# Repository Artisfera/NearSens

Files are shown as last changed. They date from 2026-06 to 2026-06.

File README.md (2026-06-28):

# NearSens

NearSens is a small contactless distance meter for short range measurement. It uses a 40 kHz ultrasonic transmitter and receiver, an ATtiny1626 microcontroller, an analog receiver path, and a four-digit LCD.

The current prototype is built around a practical 5 V setup and a useful range of about 100 to 500 mm. The goal was not to make a universal sensor module. The goal was to make a simple device that can be built, tested, calibrated, and understood without hiding the hardware behind a black box.

## Main assumptions

- external 5 V DC supply
- ultrasonic time-of-flight measurement
- practical range around 100 to 500 mm
- four-digit LCD readout
- simple two-button interface
- five-point calibration stored in EEPROM
- low part count and low cost where possible
- firmware kept readable enough to debug on real hardware

## How it works

The microcontroller sends a short ultrasonic burst through the transmitter driver. The receiver picks up the echo, the analog path amplifies and filters it, and the firmware searches for a valid reflected signal in the expected time window.

The distance is calculated from echo return time. Calibration points at 100, 200, 300, 400 and 500 mm are stored in EEPROM and used to correct later measurements.

## Hardware overview

The main hardware blocks are:

- ATtiny1626 microcontroller
- ST232CDR used as the ultrasonic transmitter driver
- 40 kHz ultrasonic transmitter and receiver
- LM324 receiver path
- MC14543BDG LCD drivers
- DE117 four-digit LCD
- two tactile buttons, TS3 and TS4
- external 5 V input through PS1

R4 is a 220 ohm THT resistor added in the receiver/filter path after testing. It is listed separately in the BOM.

## Repository layout

```text
docs/
  NearSens_project_documentation.pdf
  NearSens_user_guide.pdf

hardware/
  schematic/   schematic preview and EasyEDA source
  pcb/         PCB source, outline and previews
  gerber/      PCB production files
  enclosure/   STL models

firmware/
  NearSens_1.0.0/   current firmware source

bom/
  NearSens_BOM_v1.0.0.csv

revisions/
  earlier schematic, PCB, firmware and enclosure versions

JOURNAL.md
  build log exported from Stasis
```

## Documentation

Start here:

- [Project documentation](docs/NearSens_project_documentation.pdf)
- [Use and calibration guide](docs/NearSens_user_guide.pdf)
- [Bill of materials](bom/NearSens_BOM_v1.0.0.csv)

The `revisions` folder is an archive of earlier work. The current files are in `docs`, `hardware`, `firmware` and `bom`.

## Firmware

Current firmware is in:

```text
firmware/NearSens_1.0.0/
```

It was prepared for Arduino IDE with the megaTinyCore package and ATtiny1626 running at 5 MHz.

Main controls:

- TS3 makes a measurement
- TS4 toggles the 75 mm reference correction
- holding TS3 and TS4 enters calibration
- five quick TS3 clicks toggle RAW mode

Normal use does not need a computer. A 5 V DC supply is enough to power the prototype and take measurements.

## Calibration

Calibration uses five points:

```text
100 mm
200 mm
300 mm
400 mm
500 mm
```

Use a flat, hard target placed perpendicular to the ultrasonic transducers. Soft materials, angled surfaces and nearby reflections can make the result unstable.

## Status

This repository contains the v1.0.0 prototype documentation, firmware and hardware files. It is a working prototype, not a finished commercial product. Some parts of the history are kept in `revisions` because they show how the design changed over time.

## License

NearSens is source-available for non-commercial community use.

Firmware and source code are licensed under the PolyForm Noncommercial License 1.0.0. The official license text is in [LICENSE](LICENSE) and [LICENSES/PolyForm-Noncommercial-1.0.0.txt](LICENSES/PolyForm-Noncommercial-1.0.0.txt).

Hardware design files, PCB files, CAD files, Gerbers, documentation, BOM, images and journal files are licensed under Creative Commons Attribution-NonCommercial-ShareAlike 4.0 International. The official license text is in [LICENSES/CC-BY-NC-SA-4.0.txt](LICENSES/CC-BY-NC-SA-4.0.txt).

Required attribution: `NearSens by Patryk Ankudowicz (Artisfera)`.

Commercial use is not granted by these licenses. Contact the author for separate permission.

## Author

Patryk Ankudowicz (Artisfera)

37985225-6b87-468d-819c-fa1fb3e9c759

0deb3eeb-d8f6-42e3-ba4b-9c512cce84f7

9b99e4cb-7a58-41e2-9bc0-3cf050692205
=======

37985225-6b87-468d-819c-fa1fb3e9c759
0deb3eeb-d8f6-42e3-ba4b-9c512cce84f7
9b99e4cb-7a58-41e2-9bc0-3cf050692205
>>>>>>> b40b73c956a27c340263484fec96b0e8252ce2aa

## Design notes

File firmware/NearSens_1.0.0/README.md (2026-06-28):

NearSens 1.0.0 - microcontroller firmware

Environment
Arduino IDE with the megaTinyCore package
Microcontroller: ATtiny1626
Prototype v1.0.0 clock: 5 MHz

Main file
NearSens_1.0.0.ino

File split
NearSens.h - pin definitions, constants, states and function declarations
Buttons.cpp - TS3, TS4, RAW mode, 75 mm correction and calibration entry handling
Calibration.cpp - 100/200/300/400/500 mm calibration and EEPROM storage
Display.cpp - LCD handling and display codes
Hardware.cpp - pin setup, ADC setup, TX path power control and sleep handling
Measurement.cpp - ultrasonic measurement and echo qualification
State.cpp - firmware state variables
Utils.cpp - helper functions

Main features
Measurement after pressing TS3
75 mm correction toggled with TS4
RAW mode after five quick TS3 clicks
Calibration after holding TS3 and TS4
Calibration point storage in EEPROM
LCD codes 8888, 1111, 4000-4007, 7000 and 7001

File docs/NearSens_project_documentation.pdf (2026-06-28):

# NearSens - project documentation

Contactless distance meter 100-500 mm

Field | Value
Author | Patryk Ankudowicz
Document version | 1.0
Date | 18.06.2026
Schematic version | v1.0.0
PCB version | v1.2.0
Firmware version | v1.0.0

### 1. Purpose and scope

This document describes the construction and operation of the NearSens prototype. It covers the electronics, firmware, calibration, PCB production files, bill of materials and mechanical models used to build the device.
NearSens measures the distance to an object with an ultrasonic time-of-flight method over the practical 100-500 mm range. The result is shown on a four-digit LCD. The circuit is powered from an external 5 V DC source.

### 2. Prototype status

Area | Status
Schematic | v1.0.0, SVG file and EasyEDA JSON source
PCB | v1.2.0, EasyEDA JSON source, board outline DXF and Gerber
Firmware | v1.0.0, Arduino/C++ source code
Enclosure | STL model v1.0.0 and bracket
BOM | CSV
Revisions | earlier schematic, PCB, firmware and enclosure files in the revisions folder

### 3. Design assumptions

Area | Selected solution
Measurement method | ultrasonic echo time-of-flight measurement
Practical range | 100-500 mm
Power supply | 5 V DC through connector PS1
Result display | four-digit LCD
Controls | two buttons: TS3 and TS4
Calibration | 100, 200, 300, 400 and 500 mm points
Settings memory | microcontroller EEPROM
Microcontroller clock | 5 MHz
CAD documentation | schematic and PCB in EasyEDA JSON
PCB production | Gerber files v1.2.0
Mechanical parts | STL models of the enclosure and bracket

### 4. Measurement principle

The microcontroller generates a short burst that drives the ultrasonic transmitter. The wave reflects from the object surface and returns to the receiver. The receiver signal passes through the analog path and is then sampled by the microcontroller ADC. Distance is calculated from echo return time. The firmware analyses a series of samples and rejects results that do not meet stability conditions or appear outside the detection window. After calibration, the result is corrected using points stored in EEPROM.

### 5. Functional blocks

Block | Role in the device
5 V DC input | prototype power supply
ATtiny1626 | measurement control, ADC, LCD, buttons and EEPROM
ST232CDR | ultrasonic transmitter drive
40 kHz transmitter | ultrasonic burst emission
40 kHz receiver | echo reception from the object
LM324 | analog receiver path
MC14543BDG | LCD segment driving
LCD DE117 | result and diagnostic code display
TS3 and TS4 | measurement, calibration and mode handling

### 6. Transmit path

The transmit path uses the ATtiny1626, the ST232CDR and a 40 kHz ultrasonic transducer. The microcontroller drives the T1IN and T2IN inputs of the ST232CDR. This drive method gives stronger transducer excitation than direct driving from a microcontroller port.
The firmware sends a 16-cycle burst. The drive half-period is 12 us, which gives excitation near 41.7 kHz. The detection window is limited to the range needed for 100-500 mm operation, so late reflections unrelated to the measurement are not analysed.

### 7. Receive path

The receive path consists of the ultrasonic receiver, LM324 stages and the microcontroller ADC input. The receiver signal is analog, so it is not treated as a single logic state. The firmware searches for the echo in a series of samples and checks amplitude and result stability.
In the prototype, R4 has a value of 220 ohm. This part is listed separately in the BOM.

### 8. Microcontroller and firmware

The firmware is located in firmware/NearSens_1.0.0. The main sketch file is NearSens_1.0.0.ino. The remaining files split the code into button handling, calibration, display, hardware setup, measurement, device state and helper functions.
The code is prepared for Arduino IDE with the megaTinyCore package. The package contains source files. Build configuration and compiled output files are not recreated in this documentation.
The J_PROG pad exposes the ATtiny1626 UPDI line. In the prototype, the series resistor for this line is not soldered on the board, so programming requires an external 4.7 kOhm resistor in the UPDI wire.
File | Code area
NearSens.h | pin definitions, constants, states and function declarations
Buttons.cpp | TS3, TS4, RAW mode, 75 mm correction and calibration entry handling
Calibration.cpp | 100-500 mm calibration and EEPROM
Display.cpp | LCD handling and display codes
Hardware.cpp | pin setup, ADC setup, TX path power control and sleep handling
Measurement.cpp | ultrasonic measurement and echo qualification
State.cpp | firmware state variables
Utils.cpp | helper functions

### 9. User interface

The device can be started and checked without a computer. A 5 V DC power supply is enough for a basic test.

Element | Function
PS1 | 5 V DC power input
TS3 | single measurement and calibration point storage
TS4 | 75 mm correction toggle and calibration point selection
TS3 + TS4 | enter calibration after holding for about 5 s
5 TS3 clicks | toggle RAW mode
LCD | measurement result, work modes and error codes

### 10. Calibration

Calibration uses the 100, 200, 300, 400 and 500 mm points. For each point, the device performs a series of measurements and stores the accepted value in EEPROM. Later measurements are corrected using the stored points.
Calibration quality depends on the test setup geometry, object surface, transducer alignment and ambient conditions. The object should be flat, hard and perpendicular to the transducers.

### 11. Temperature effect

The speed of sound in air depends on temperature. The prototype does not measure ambient temperature, so the firmware does not compensate for this effect. This does not block operation in the selected range, but it limits claims of accuracy independent of test conditions.
A possible improvement would be adding a temperature sensor and using its reading when converting time of flight to distance.

### 12. Display codes

Code | Meaning
8888 | device startup and ready for measurement
1111 | calibration point stored correctly
7001 | RAW enabled
7000 | RAW disabled
0 _ 75 | 75 mm reference correction disabled
1 _ 75 | 75 mm reference correction enabled
4000 | general no-result code
4001 | no stable echo
4002 | echo too early, crosstalk or transmitter blanking
4003 | echo outside technical range
4004 | calibration error
4005 | no valid calibration data
4006 | calibration sample spread too large
4007 | ADC/RX receiver path error

### 13. PCB and production files

Hardware documentation is located in the hardware directory. EasyEDA JSON files are the CAD sources for the schematic and PCB. Gerber files are intended for PCB fabrication.

Folder | Contents
schematic | schematic SVG and EasyEDA JSON source
pcb | EasyEDA PCB source, DXF outline and layer previews
gerber | PCB production files v1.2.0
enclosure | STL models of the enclosure and bracket

### 14. Mechanical documentation

The enclosure and bracket are mechanical parts of the prototype. Their cost is not included in the electronic parts and PCB BOM.

File | Description
NearSens_enclosure_v1.0.0.stl | main enclosure model
NearSens_bracket_v1.0.0.stl | bracket used during assembly

### 15. BOM

The BOM is in the bom folder in CSV format. It includes electronic parts and the PCB. Prices are given in USD.
The total value of the BOM items is 11.7949 USD. The enclosure is not included in this value. R4 is listed in the BOM as a part from local stock.

### 16. Project revisions

The revisions folder contains earlier versions of the schematic, PCB, firmware and enclosure. This material shows the development process. Current production files are located in the main docs, hardware, firmware and bom folders.

### 17. Main file contents

File or folder | Meaning
docs/NearSens_user_guide.pdf | startup, use and calibration
docs/NearSens_project_documentation.pdf | project description
hardware/schematic | schematic and CAD source
hardware/pcb | PCB sources, outline and previews
hardware/gerber | PCB production files
hardware/enclosure | STL models
firmware/NearSens_1.0.0 | source code
bom | bill of materials
revisions | earlier mechanical, firmware, schematic and PCB revisions

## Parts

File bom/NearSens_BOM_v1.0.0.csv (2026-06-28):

NAME | QUANTITY | DISTRIBUTOR | TOTAL COST (USD) | LINK | Designator
1 uF MLCC capacitor, 0805, 10% | 5 | TME | 0,2895 | https://www.tme.eu/pl/en/details/cl21b105kafnnng/mlcc-smd-capacitors/samsung/ | C1,C2,C3,C4,C5
10 uF MLCC capacitor, 1206, 10% | 1 | TME | 0,0908 | https://www.tme.eu/pl/en/details/grm31cr61e106ka12l/mlcc-smd-capacitors/murata/ | C7
100 nF MLCC capacitor, 0603, 10% | 6 | TME | 0,1279 | https://www.tme.eu/pl/en/details/cl10b104kb8wpnc/mlcc-smd-capacitors/samsung/ | C8,C10,C11,C12,C13,C19
10 nF MLCC capacitor, 0603, 10% | 3 | TME | 0,0307 | https://www.tme.eu/pl/en/details/cl10b103kb8nnnc/mlcc-smd-capacitors/samsung/ | C14,C15,C18
1 nF MLCC capacitor, 0603, 10% | 2 | TME | 0,0212 | https://www.tme.eu/pl/en/details/cl10b102kb8nnnc/mlcc-smd-capacitors/samsung/ | C16,C17
DE 117-TS-20/7,5/V four-digit LCD | 1 | TME | 1,5441 | https://www.tme.eu/pl/details/de117-ts-20_7.5/wyswietlacze-lcd-cyfrowe/display-elektronik/de-117-ts-20-7-5-v/ | L1
TE0201820000G 2-pin right-angle terminal | 1 | TME | 0,3428 | https://www.tme.eu/pl/en/details/te0201820000g/pcb-terminal-blocks/amphenol-anytek/ | PS1
BC807-40 PNP transistor, SOT-23 | 1 | TME | 0,1185 | https://www.tme.eu/en/details/bc807-40-dio/pnp-smd-transistors/diotec-semiconductor/bc807-40/ | Q1
220 ohm THT resistor | 1 | local stock | 0 |  | R4
1 kohm resistor, 0603, 1% | 1 | TME | 0,0088 | https://www.tme.eu/pl/details/smd0603-1k-1%25/rezystory-smd/royalohm/0603saf1001t5e/ | R1
75 kohm resistor, 0603, 1% | 2 | TME | 0,0296 | https://www.tme.eu/pl/en/details/smd0603-75k-1%25/smd-resistors/royalohm/0603saf7502t5e/ | R2,R5
10 kohm resistor, 0603, 1% | 3 | TME | 0,0279 | https://www.tme.eu/pl/en/details/smd0603-10k-1%25/smd-resistors/royalohm/0603saf1002t5e/ | R3,R11,R17
100 kohm resistor, 0603, 1% | 1 | TME | 0,0136 | https://www.tme.eu/pl/en/details/smd0603-100k-1%25/smd-resistors/royalohm/0603saf1003t5e/ | R16
56 kohm resistor, 0603, 1% | 1 | TME | 0,0148 | https://www.tme.eu/pl/en/details/smd0603-56k-1%25/smd-resistors/royalohm/0603saf5602t5e/ | R18
6,2 kohm resistor, 0603, 1% | 1 | TME | 0,0273 | https://www.tme.eu/pl/en/details/crcw06036k20fktabc/smd-resistors/vishay/ | R19
7,5 kohm resistor, 0603, 1% | 1 | TME | 0,0062 | https://www.tme.eu/pl/en/details/rc0603fr-077k5/smd-resistors/yageo/rc0603fr-077k5l/ | R20
4,7 kohm resistor, 0603, 1% | 1 | TME | 0,0119 | https://www.tme.eu/pl/en/details/smd0603-4k7-1%25/smd-resistors/royalohm/0603saf4701t5e/ | R21
DS1041-01-113KKA16010 tactile switch | 2 | TME | 0,1517 | https://www.tme.eu/pl/details/tact4101-113160-a/mikroprzelaczniki-tact/connfly/ds1041-01-113kka16010/ | TS3, TS4
ST232CDR line driver, SO-16 | 1 | TME | 0,8312 | https://www.tme.eu/pl/details/st232cdr/uklady-scalone-rs232-rs422-rs485/stmicroelectronics/ | U1
ATtiny1626-SU microcontroller, SO-20 | 1 | TME | 1,3805 | https://www.tme.eu/pl/en/details/attiny1626-su/8-bit-avr-family/microchip-technology/ | U2
LM324DT quad operational amplifier, SO-14 | 1 | TME | 0,1897 | https://www.tme.eu/pl/en/details/lm324dt/smd-operational-amplifiers/stmicroelectronics/ | U4
MC14543BDG LCD decoder/driver, SO-16 | 4 | TME | 1,8176 | https://www.tme.eu/pl/en/details/mc14543bdg/decoders-multiplexers-switches/onsemi/ | U5,U6,U7,U8
16 mm ultrasonic transducer set, TX + RX, 40 kHz | 1 | Botland | 3,0586 | https://botland.com.pl/ultradzwiekowe-czujniki-distance/1209-czujniki-ultradzwiekowe-16mm-komplet-5904422355920.html | UT-T, UT-R
NearSens PCB v1.2.0 | 1 | JLCPCB | 1,66
TOTAL |  |  | 11,7949

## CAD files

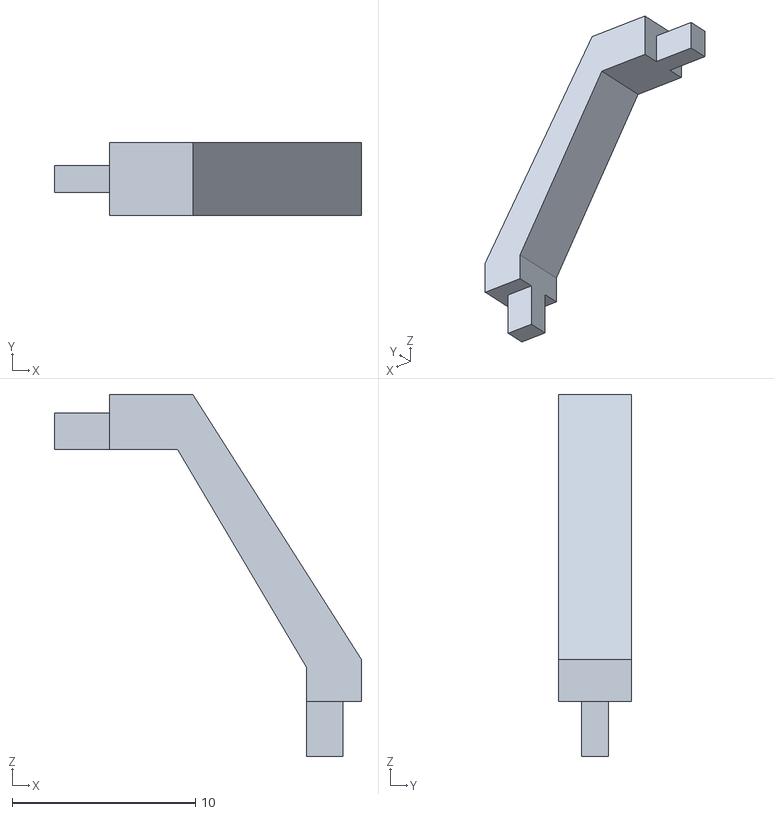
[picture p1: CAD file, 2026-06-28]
hardware/enclosure/NearSens_bracket_v1.0.0.stl
16.7 x 4.00 x 19.8

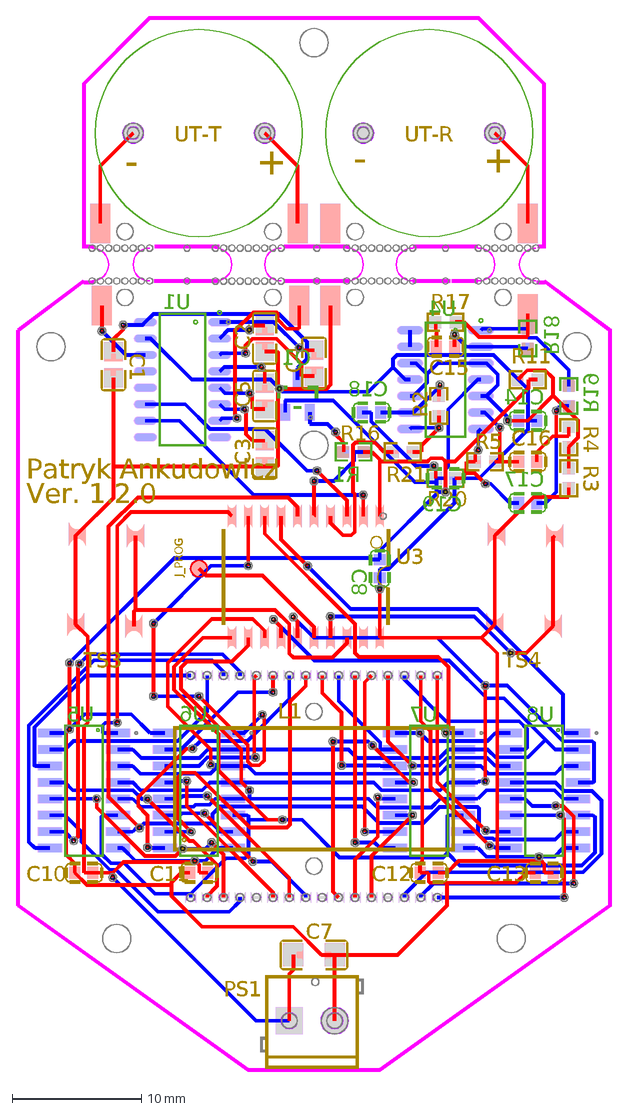
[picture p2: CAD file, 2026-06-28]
hardware/pcb/NearSens_pcb_outline_v1.2.0.dxf
Patryk Ankudowicz
Ver. 1.2.0
L1
R5
R2
R4
R3
R11
R17
R21
C16
C15
R20
PS1
J_PROG
C7
C10
C11
C12
C13
R16
TS3
TS4
C1
C2
C3
C4
C5
U3
C14
R18
UT-R
-
+
Q1
R1
U1
U5
U6
U7
U4
C8
UT-T
C17
C18
C19
R19
U8

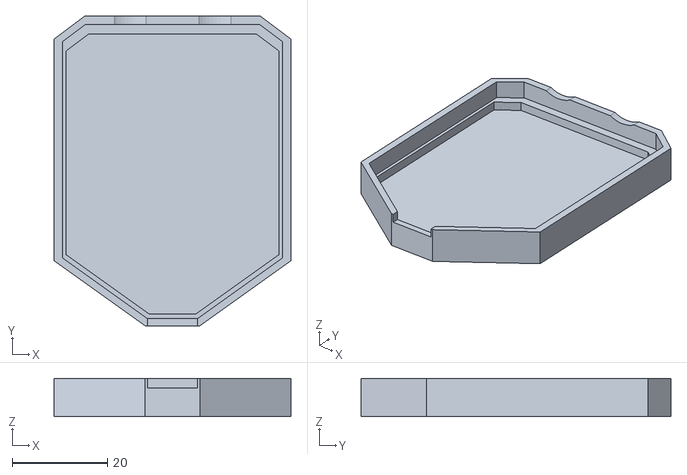
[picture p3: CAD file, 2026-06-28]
revisions/enclosure/Nearsens-cover-0.2.1.stl
49.7 x 65.0 x 8.00

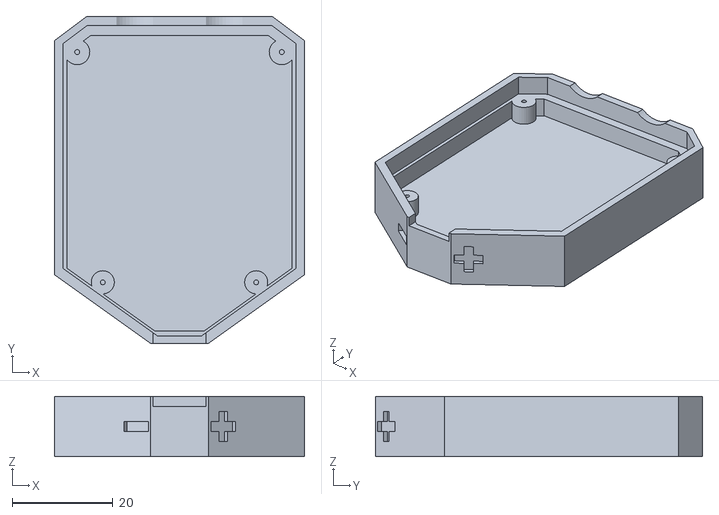
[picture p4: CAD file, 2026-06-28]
hardware/enclosure/NearSens_enclosure_v1.0.0.stl
49.7 x 65.0 x 12.0

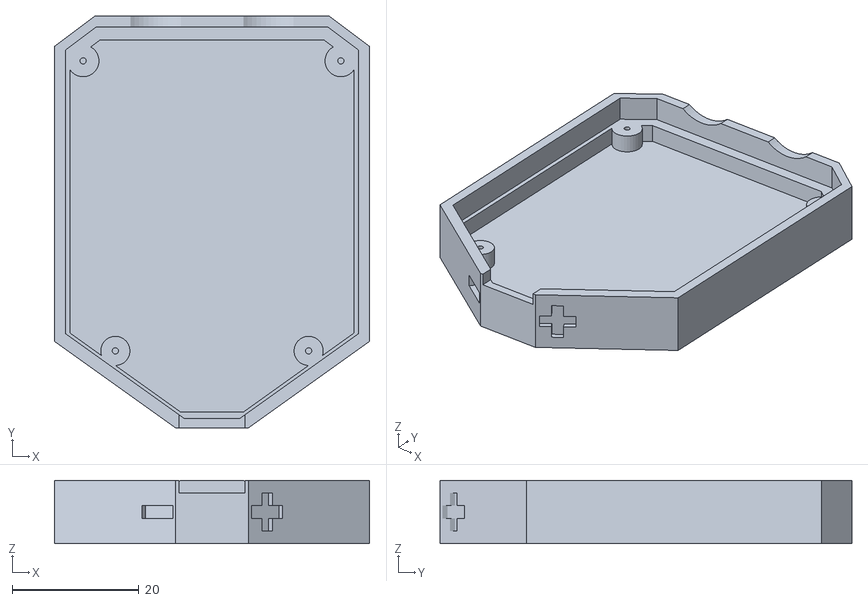
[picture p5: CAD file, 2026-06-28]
revisions/enclosure/Nearsens-cover-0.4.0.stl
49.7 x 65.0 x 10.0

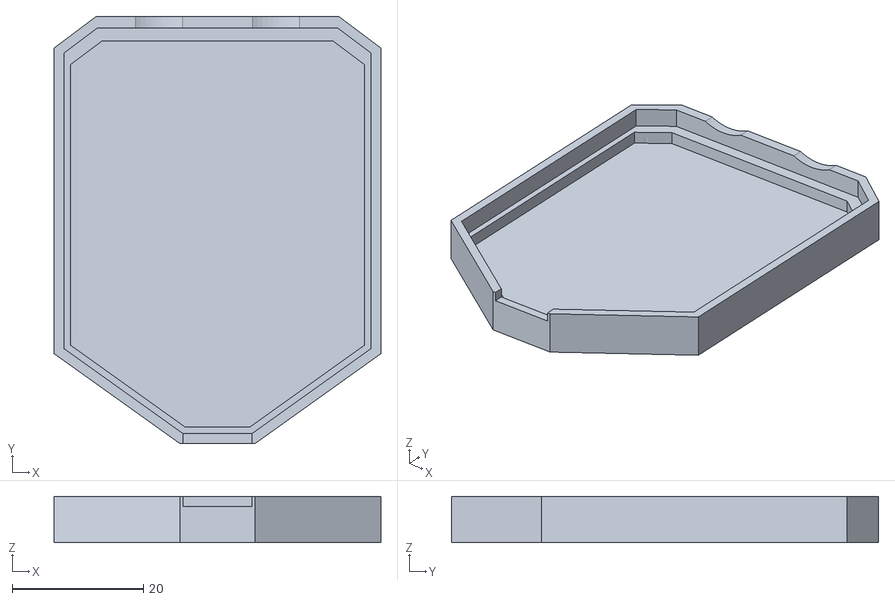
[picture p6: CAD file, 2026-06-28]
revisions/enclosure/Nearsens-cover-0.2.0.stl
49.7 x 65.0 x 7.00

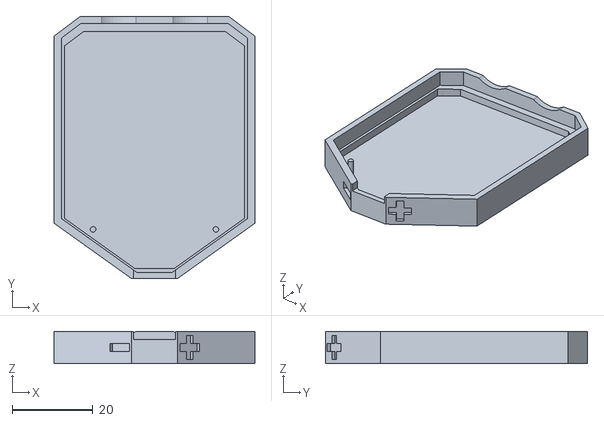
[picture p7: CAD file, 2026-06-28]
revisions/enclosure/Nearsens-cover-0.3.0.stl
49.7 x 65.0 x 8.00

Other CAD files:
revisions/enclosure/Nearsens-cover-0.1.0.stl
hardware/enclosure/NearSens_enclosure_v1.0.0.f3d

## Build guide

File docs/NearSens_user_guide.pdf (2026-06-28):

# NearSens - use and calibration guide

NearSens is a 100-500 mm distance meter prototype. It uses ultrasonic measurement and shows the result on a four-digit LCD. This document describes startup, basic measurement, RAW mode, 75 mm correction, calibration and the codes shown by the device.

### 1. Power supply

Power the device from a 5 V DC supply. Connect power to the PS1 screw terminal on the PCB. Keep polarity according to the markings on the prototype enclosure.
After power-up, the display shows code 8888. This means device startup and readiness for measurement.

### 2. Test object preparation

For testing, use a flat, hard object placed as perpendicular as possible to the ultrasonic transducers.
The recommended object surface is about 20 x 20 cm or larger. This matches the example test object and gives a larger, more repeatable reflection surface for the ultrasonic wave.
For a normal test, set the distance from the front face of the ultrasonic transducers. In this setup, the 75 mm correction should be disabled.
Enable the 75 mm correction only when the result should be referenced to the rear wall of the enclosure, meaning the end of the device opposite to the transducers.

### 3. Basic measurement

1. Connect the 5 V DC supply.
2. Wait for code 8888.
3. Place the test object at the selected distance.
4. Briefly press TS3.
5. Read the result from the LCD.
The result is shown in millimetres. During measurement, the display may show a short digit animation. After measurement, either the result or an error code appears.
A computer, programmer or Arduino IDE is not needed for a normal test. A 5 V DC supply is enough.

### 4. Buttons

Element | Action
TS3 | single measurement; stores the current point during calibration
TS4 | toggles 75 mm correction; selects the calibration point during calibration
TS3 + TS4 | enters calibration after holding for about 5 s
5 quick TS3 clicks | enables or disables RAW mode

### 5. 75 mm reference correction

The 75 mm correction changes only the value shown on the LCD. It does not change calibration points stored in EEPROM and does not apply in RAW mode.
In BODY mode, the firmware subtracts 75 mm from the normal result. This only makes sense when the measurement should be referenced to the rear wall of the enclosure, not to the front of the transducers.
Codes shown after pressing TS4:
Code | Meaning
0 _ 75 | 75 mm correction disabled
1 _ 75 | 75 mm correction enabled

For measurement from the transducer front face, use mode 0 _ 75.

### 6. RAW mode

RAW mode shows the raw result before calibration correction and before the 75 mm reference correction. It is used for measurement path diagnostics.

To toggle RAW, quickly press TS3 five times.

Code | Meaning
7001 | RAW mode enabled
7000 | RAW mode disabled

RAW should be disabled for normal measurement. RAW is only for diagnostics.

### 7. Calibration

Calibration stores reference points in the microcontroller EEPROM. Recommended calibration points are:
- 100 mm
- 200 mm
- 300 mm
- 400 mm
- 500 mm
Procedure:
1. Hold TS3 and TS4 together for about 5 s.
2. Select the calibration point with TS4.
3. Place the object at the selected distance.
4. Press TS3 to store the point.
5. Repeat for the next points.
Code 1111 means that the calibration point was stored correctly. If an error code appears, check object placement, distance and echo stability, then repeat the point storage.
Calibration should be performed in the same setup in which later measurements will be made. The prototype does not have an air temperature sensor, so temperature changes can affect the result by changing the speed of sound.

### 8. LCD codes

Code | Meaning
8888 | device startup and ready for measurement
1111 | calibration point stored correctly
7001 | RAW mode enabled
7000 | RAW mode disabled
0 _ 75 | 75 mm correction disabled
1 _ 75 | 75 mm correction enabled
4000 | general no-result code
4001 | no stable echo
4002 | echo too early, crosstalk or transmitter blanking
4003 | echo outside technical range
4004 | calibration error
4005 | no valid calibration data
4006 | calibration sample spread too large
4007 | ADC/RX receiver path error

### 9. If the result is unstable

- check that the object is flat and perpendicular to the transducers
- increase the test object surface area
- avoid soft or sound-absorbing materials
- limit reflections from nearby objects
- check that the distance is within 100-500 mm
- calibrate at 100, 200, 300, 400 and 500 mm
- if needed, enable RAW and compare the raw result with the calibrated result

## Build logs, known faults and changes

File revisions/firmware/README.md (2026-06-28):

# NearSens firmware archive

This directory contains the NearSens firmware versions that were found, archived and preserved. They were collected from working copies, archives and older saved project variants.

There may be gaps in the numbering. During development, some versions were overwritten or were not saved as separate packages. Some versions also have several different variants, placed in separate subfolders.

This is a working archive. Directory names such as final, final-safe or final-tuned come from testing stages and do not mark the current project release. The current firmware is in `firmware/NearSens_1.0.0`.

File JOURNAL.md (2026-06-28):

<!--
  This journal is auto generated by Stasis.
-->

# 6/28/2026 11 AM - 11 NearSens - Programming

_Time spent: 7h_

The last thing before the final working version was programming. Somehow, this turned out to be the longest part of the whole project.

In theory it sounded simple. Send an ultrasonic pulse, measure the return time, calculate the distance from:

`D = (T * C) / 2`

Then show the final value on the LCD. That was the idea.

In practice it was much more annoying. I was trying to get close to 1 mm resolution and still have an interface that was not painful to use, so every small change had to be tested on the real board. Then adjusted. Then tested again. I do not even know how many versions I made, maybe around 30, but eventually the sensor finally started measuring properly.

The important part was not just the formula. The hard part was making the device detect the actual reflected signal, not random noise, and doing it in the right time window. In the end, a 5-point calibration turned out to be necessary, together with a lot of tuning of the detection parameters.

I am more of an electronics person than a programmer, so the code was written with help from an LLM. But in a physical project like this, that only helps with writing the code itself. It cannot test the board for me, choose what the signal should look like, or figure out why the measurement fails. I still had to understand the circuit, test every version, and decide what actually needed to be changed.

96406f26-3eea-4077-9119-57f7e37da816

# 6/28/2026 11 AM - 10 NearSens - Design enclosure

_Time spent: 3h_

After the board was soldered, the last thing left before programming was the enclosure.

It was more important than it may sound at first, because the circuit had to stand straight and stay stable. The small PCB with the transducers was also too easy to bend without support, so the case helped protect it a bit. Without a case, it was also much easier to accidentally short something on the desk or while handling the board. It also gave me a clean place to mark + and - for the external 5 V power input.

Designing the enclosure was not that hard. I exported the PCB outline as a DXF, imported it into Fusion 360, thought for a while about how it should sit, and then started printing test versions. Of course, the first one did not fit. It never does.

Most of the problems were small fitting issues, wall thicknesses, and finding screws that actually matched. Luckily, past me had a good idea to sort screws from old broken devices instead of throwing them into one random box. I found two that fit perfectly, so that finally paid off.





37985225-6b87-468d-819c-fa1fb3e9c759

0deb3eeb-d8f6-42e3-ba4b-9c512cce84f7

9b99e4cb-7a58-41e2-9bc0-3cf050692205

# 6/28/2026 10 AM - 9 NearSens - Soldering

_Time spent: 4h_

The PCB finally arrived, so there was no more excuse. After all the schematic work, PCB changes and checking parts, I could finally solder the actual board.

And honestly, the feeling of holding my own PCB was really hard to describe. It was not just some EasyEDA project anymore. It was a real thing, with my shape, my mistakes, my routing, everything. That was just cool.

Soldering also went way better than I expected. I always thought SMD with a normal soldering iron would be much worse, but it is honestly not that different from THT. The main trick is just using enough flux and not trying to be too "clean" from the start. If there is flux, the solder usually goes where it should.

0603 parts were the only ones that got a bit annoying. They are still doable by hand, but at that point I used hot air a little, mostly to make the joints sit nicer. It worked well, but I had to be careful, because ICs obviously do not enjoy being cooked. Also, I learned that the LCD is not something I should clean aggressively with alcohol, so that part needed more care.

During testing I also found one actual hardware problem. R4 had to be changed to 220 ohm so the filter would work around 40 kHz properly. Of course, the PCB was already made, so I had to improvise a bit and solder a THT resistor into a board that was not really meant for it. It sounds ugly, but it actually came out really well and looks much cleaner than I expected.

The school helped a lot here. I got a proper place, time and tools to solder it calmly, which was much better than trying to do it on a dresser in the middle of moving stuff around.

Sadly, Hack Club Lapse has some technical problems right now, so I cannot upload the timelapse yet. I still recorded the work, and I will try to add it when Lapse starts working again.

1ff468b6-0fb5-475f-9e92-c70972ae4fa8

185b35a0-f077-4486-a81d-ce625f59f356

9ec08199-52ea-4dec-ba38-2d6b17a2ea2f

# 6/27/2026 10 PM - 8 NearSens - Full rebuild

_Time spent: 7h_

I had to put NearSens aside for almost two months. School stuff and moving took over, so I simply did not have enough time or headspace to continue the project properly.

That break was actually good for the project. I kept thinking about it in the background, and when I finally came back to it, I looked at the whole design differently. I did not want to just continue the old version. I wanted to make the final one more practical and easier to build.

The first thing I returned to was the PCB. In the final version, I changed the board so it works from an external +5 V supply. I also stopped making the electronics depend on a separate enclosure at that stage. The ultrasonic transducers can be connected to the main board through solder pads, which keeps the build simpler and makes testing much easier.

I also spent a lot of time going back through the schematic and choosing the final parts. There was still quite a lot to fix, especially in the receiver path. The amplification and filtering of the received signal needed more work than I gave them in the early version, so this stage was mostly about cleaning up the design and turning it into something I could actually assemble and debug.




# 4/5/2026 10 PM - 7 NearSens - PCB correction

_Time spent: 1h_

Hey! I did not have much time today, but I still managed to make some progress.

Most of the session was spent adjusting the component placement on the PCB and cleaning things up a bit. While doing that, I found a better tact switch option and a better PNP transistor for the design.

I also quickly made a footprint that fit the project better, so even though this was not a huge milestone day, it still helped move the design forward.





# 4/5/2026 9 PM - 6 NearSens - CAD & Design PCB

_Time spent: 2.666666666666667h_

Happy Easter, but I'm not breaking the streak!

Today was Easter, so I had to spend some time at home helping out. Because of that, out of almost 5 hours of timelapse footage, only about one hour turned out usable :p

After yesterday's lessons, I went back to Fusion 360, and honestly, it went much better. I managed to make the first v0.1.0 version of the enclosure outline. It might not sound like a huge step, but it gave me something very important: real dimensions and a real shape to work around.

I like when distances, spacing, and proportions in a project actually make sense. Even the "random" dots visible in the timelapse were not really random. I matched them against my hand placed on a properly scaled screen, then aligned everything carefully. That gave me a shape that should actually feel comfortable and ergonomic instead of just looking okay on screen.

Then came the part I was really waiting for: PCB work. I couldn't start it properly before knowing the enclosure size, so getting the outline done first was necessary. PCB progress went fairly well, although the board dimensions surprised me more than expected. Because of that, I'll most likely have to replace the potentiometers with fixed resistors to save space.

And finally, one more design question: do I really need 2xAA?

This distance meter should use extremely little power, likely below 2 mW on average, so even coin cells would technically be enough. Still, I'm leaning toward standard batteries because they are cheap, common, and easy to replace anywhere. You might ask: "It's 2026 and you still want disposable batteries instead of Li-ion or LiPo?" Honestly, rechorgeable cells do not fit this project well. They raise the cost, need extra charging electronics, age over time, and in measurement tools that are supposed to work when you need them, dead built-in batteries are just annoying. A replaceable battery makes more sense here.

While writing this, I think I've already made the decision: I'll switch from AA to AAA. AA is simply overkill here, while AAA is still common, easier to fit, and much more reasonable for this kind of device.






# 4/4/2026 9 PM - 5.5 NearSens - Fusion360>OnShape

_Time spent: 0.5833333333333334h_

Today I planned to finally start turning my hammerhead-inspired enclosure concept into a proper CAD sketch, but I ran into two important problems.

First, I realized the hammerhead shape is probably not the best choice after all. For about 1 mm accuracy in the 5-50 cm range, the distance between the transmitter and receiver should stay around 20 mm. That means the front of the enclosure cannot be as wide as I first imagined if I also want to fit the LCD in a sensible way. At this point the design is starting to look closer to a regular shark than a hammerhead, so I will most likely need to rethink the whole visual concept.

The second problem was the CAD tool itself. Since I need something browser-based, I tried working in Onshape, but so far it does not feel as intuitive or comfortable to me as Fusion 360, which I am much more used to. I am still going to give Onshape a fair chance and spend some time learning it better, but if Fusion 360 still feels clearly better for this kind of work, I will continue the enclosure design there instead.





# 4/3/2026 9 PM - 5 NearSens - Finishing schematic

_Time spent: 0.9833333333333333h_

Huge milestone.. the project schematic is officially finished! I made some last-minute adjustments after discovering a cheaper 4-digit display (upgraded from 3 digits!).

Since the goal is to keep this project as low-cost and low-power as possible, the final PCB will only use 3 digits for now. However, I decided to include the 4th decoder in the design and leave some space on the board for future-proofing. This way, I can experiment with it later! I also spent some time polishing and aligning the schematic to make it look professional and consistent.
Schematic_NearSens_2026-04-03



# 4/2/2026 2 PM - 4 NearSens - Design concept

_Time spent: 0.4166666666666667h_

EasyEDA was throwing 504/502 errors today, so to keep my momentum going, I started working on the enclosure design. I love looking for inspiration in nature:) I thought about dragonflies or mantis shrimps, but they are way too complex.

Instead, I chose a Hammerhead Shark. They have amazing vision and the shape fits my project perfectly! Since I didn't have my drawing tablet next to me, sketching was a struggle. I tried Onshape, but CAD was too stiff for a first sketch. I went back to Krita, found some mouse smoothing tools, and finally got the concept down. It's just a rough idea for now, but I'm happy with the direction!




# 3/31/2026 11 PM - 3 NearSens - Make own footprints

_Time spent: 1.05h_

Yo! Today I built a custom footprint for the transducers. I'm repurposing the ones from a cheap HC-SR04 module because they are super budget-friendly. I wasn't sure about the exact specs, so I measured them myself to get the footprint right (as you can see in the photos). Remember, the main goal of this project is to keep the total cost as low as possible!

I also found a cheap LCD screen I wanted to use, but EasyEDA didn't have the footprint or symbol for it. Making my own took way more time than I expected. Design work is a real time sink, but it was definitely worth it. 







# 3/30/2026 11 PM - 2 NearSens

_Time spent: 1h_

Hey! I did not manage to get too much done yet. I mostly cleaned up the leftover stuff from the last update, adjusted some of the footprints, and started putting together the BOM. Next time I will finish that up and then move on to Microchip Studio:)





# 3/17/2026 10 PM - 0.9.0

_Time spent: 4.8h_

v0.9.0

Finally got the first schematic and overall idea for this project down!!

Right now it is still very much a rough first version, more "this is the direction" than "this is finished", but I am really happy to finally have the concept out of my head and onto something real.

Still doing research, still figuring stuff out, still tweaking things, but it feels like this project is actually starting now.

Next step: putting together an AliExpress cart and slowly turning this idea into something real :)

(This pcb is soo bad, I know...)


Schematic_NearSens_2026-03-17

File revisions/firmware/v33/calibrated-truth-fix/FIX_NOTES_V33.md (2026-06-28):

# NearSens v33 calibrated truth fix

Base: v32 codebase, but NearSens.h profile was replaced with the user-supplied v24-style header and EEPROM_VERSION was bumped to 18.

Main fix:

- Calibration no longer chooses the sample closest to the requested target.
- Calibration stores the best real cluster, or the median of real readings if no cluster exists.
- This prevents fake-perfect 100 mm calibration that can make 80/110/130/140 mm all collapse toward 100 mm.

Measurement fix:

- Packet cluster selection no longer blindly takes the first stable cluster.
- It chooses the compact cluster with most members, then smallest spread, then earlier median as tie-break.

Kept:

- peakUs-based ToF
- TS4 offset state 0 _ 75 / 1 _ 75
- RAW mode
- selectable calibration point
- no forced F_CPU

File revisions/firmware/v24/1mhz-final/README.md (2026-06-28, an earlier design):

# NearSens v24 1 MHz final

Keep all `.cpp` files and `NearSens.h` in this folder because Arduino compiles them together as one sketch.

Use Arduino IDE with megaTinyCore and ATtiny1626 selected. Set the clock according to the test profile before compiling.

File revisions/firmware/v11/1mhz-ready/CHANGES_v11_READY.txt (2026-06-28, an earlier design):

NearSens v11 ready, change list compared with v10

1. Calibration
- The previous model used 100/300/500 points and piecewise interpolation.
- If raw500 was stored close to raw300, the code could silently use a wrong segment or extrapolate, which could produce a 35 cm -> 30/31 cm effect.
- v11 uses only one 500 mm point as a global offset.
- raw500 must be within the 380-650 mm window. If not, calibration shows 4004 and does not write EEPROM.

2. EEPROM
- Calibration data version was changed to 6.
- Old versions are not loaded, to avoid carrying damaged calibration into this firmware.

3. Buttons
- TS3 short press: measurement.
- TS4 short press: toggle front/body reference.
- TS3+TS4 for 5 s: 500 mm calibration.
- Individual long press of TS3 or TS4 no longer stores 100/300 points.

4. Measurement
- Far fallback is disabled.
- Measurement cluster was reduced from 65 mm to 25 mm.
- Calibration cluster was reduced from 35 mm to 25 mm.

5. LCD and power
- Idle 8888 is intentional.
- Deep sleep with LCD blanking was disabled in this version so the user does not see a seemingly dead LCD after some time.
- MAX232 and ADC are still turned off outside measurement.

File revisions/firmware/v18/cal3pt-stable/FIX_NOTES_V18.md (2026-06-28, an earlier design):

# NearSens v18 stable 3-point calibration

Changes compared with v17_cal2pt:

- restored 3-point calibration at 100/300/500 mm,
- calibration works as direct piecewise interpolation from raw value to target value,
- calibration correction is not clamped,
- EEPROM was bumped to version 8 and stores raw100/raw300/raw500,
- TS3+TS4 now runs the 0100 -> 0300 -> 0500 wizard,
- measurement and calibration clusters were narrowed,
- far fallback was disabled,
- echo timeout was shortened to a range useful for 10-50 cm plus margin,
- frontend functions were kept: TS3, TS4, RAW, 75 mm offset, idle 8888, 40xx codes,
- the compile warning for F_CPU other than 1 MHz was removed. Select the clock in Arduino IDE/megaTinyCore.

After uploading, perform a full new calibration because EEPROM v7 from v17 is not compatible with v18.

Minimum test:

1. Upload the firmware.
2. After startup it should show 8888.
3. Enter calibration with TS3+TS4 held for about 5 s.
4. Calibrate 0100, 0300 and 0500.
5. Check 100, 300 and 500 mm.
6. Check 350 and 400 mm.
7. Enable RAW with five TS3 clicks.

If RAW at 350 mm shows about 300 mm, the problem is in echo detection or the RX path. If RAW shows about 350 mm but the calibrated result does not, the problem is in calibration.

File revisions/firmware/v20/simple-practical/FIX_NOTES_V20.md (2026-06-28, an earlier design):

# NearSens v20 simple practical fix

Main changes:

1. Calibration no longer requires all three points to be done at once. After entering calibration, TS4 selects point 0100/0300/0500 and TS3 stores only the currently selected point.
2. EEPROM v9 stores raw100, raw300, raw500 and validity flags for individual points. One point gives offset correction, two points give a line, and three points give piecewise 100/300/500 interpolation.
3. Measurement selects the first stable distance cluster, not the largest one. This limits the case where a false repeatable peak around 300 mm wins against the real closer target.
4. Frontend functions remain: TS3, TS4, +75 mm body reference, RAW, idle 8888 and 40xx codes.
5. The code does not force F_CPU. Select the clock in megaTinyCore/Arduino IDE settings.

Practical test:

- Upload the firmware.
- Check 8888.
- Enter RAW with five TS3 clicks.
- Check RAW at 25 cm and 30 cm. If RAW at 25 cm still shows 30 cm, the problem is in echo detection or the RX path, not in calibration.
- Enter calibration with TS3+TS4 held for 5 s.
- Select 0300 with TS4, place the object at 30 cm, then store it with TS3.
- Measure 25 cm.
- If the middle point works, add 0100 and 0500 separately.

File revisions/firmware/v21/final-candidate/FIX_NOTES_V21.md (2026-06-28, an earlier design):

# NearSens v21 final candidate

Goal of this version: simplify and stabilize RAW/measurement without removing user-facing functions.

Main changes compared with v20:

1. `measureOnePing()` no longer ends measurement at the first threshold crossing. It now scans the full echo window, collects pulse candidates and selects the strongest qualified peak.
2. During the critical ADC scan, BP/PH LCD is not serviced. BP/PH works normally outside the short receive window, but it does not switch LCD pins while sampling a weak RX signal.
3. Clusters were narrowed: `MEASURE_CLUSTER_MM = 10`, `CAL_CLUSTER_MM = 10`. This makes the firmware hide sample spread less often as a "stable" result.
4. A stricter minimum sample count was set: `MEASURE_MIN_VALID = 5`, `MEASURE_MIN_CLUSTER = 4`, `CAL_MIN_VALID = 5`, `CAL_MIN_CLUSTER = 4`.
5. The echo window was increased to `ECHO_TIMEOUT_FROM_TX_START_US = 6200UL`, but without returning to the very wide window from old versions. The goal is margin for 50 cm and analog path delay without catching far secondary reflections.
6. EEPROM version is `10`, so calibration must be repeated after uploading.

Kept features:

- TS3 as measurement.
- TS4 as front/body reference toggle.
- `DEVICE_REFERENCE_OFFSET_MM = 75`.
- RAW mode through five TS3 clicks.
- Idle `8888`.
- Calibration with point selection using TS4.
- 40xx codes.
- BP/PH LCD.
- No forced `F_CPU`. The clock is selected in Arduino IDE / megaTinyCore.

Test procedure:

1. Upload the firmware.
2. After startup, check `8888`.
3. Enable RAW with five TS3 clicks.
4. Measure 20, 25, 30, 35, 40, 45 and 50 cm in RAW.
5. Enter calibration by holding TS3+TS4 for about 5 s.
6. Select the calibration point with TS4.
7. Start by calibrating `0300`.
8. Then add `0100` and `0500` if you want full 3-point interpolation.
9. Measure 20, 25, 30, 35, 40, 45 and 50 cm again in RAW and normal mode.

If RAW still has a large error, the problem is in echo detection or the RX path, not in calibration. If RAW is good but normal mode is bad, the problem is in calibration or EEPROM data.

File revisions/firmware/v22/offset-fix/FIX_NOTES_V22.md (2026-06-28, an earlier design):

# NearSens v22 offset fix

This version fixes body reference mode logic after practical testing.

## Changes

1. `DEVICE_REFERENCE_OFFSET_MM = 75` is no longer added.
2. In `REFERENCE_BODY` mode, the offset is subtracted from the calibrated result.
3. The offset is applied exactly once and only to the normal calibrated result.
4. RAW mode has no offset.
5. Calibration samples have no offset.
6. `REFERENCE_FRONT` mode applies no offset.
7. The reference mode banner is explicit: `2001` = front / no offset, `2002` = body / subtract 75 mm.

## Fix location

The main change is in `Calibration.cpp`, in `applyCalibration()`.

Previously it was:

```cpp
if (referenceMode == REFERENCE_BODY) {
  corrected += DEVICE_REFERENCE_OFFSET_MM;
}
```

Now it is:

```cpp
if (referenceMode == REFERENCE_BODY) {
  corrected -= DEVICE_REFERENCE_OFFSET_MM;
}
```

The code comment also explains that the offset does not apply to RAW or calibration.

## Test

1. Upload the firmware.
2. After startup it should show `8888`.
3. TS4 should toggle: `2001` front, `2002` body.
4. In front mode, the result should have no offset.
5. In body mode, the result should be 75 mm lower.
6. RAW mode should show the same raw result regardless of reference mode.

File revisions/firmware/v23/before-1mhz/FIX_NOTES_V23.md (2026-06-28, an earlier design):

# NearSens v23 offset mode fix

Changes compared with v22:

1. Fixed the real reason why TS4 could look like it changed nothing. The 75 mm offset was applied inside `applyCalibration()`, so when calibration was invalid or unused, fallback `rawMm` bypassed the offset completely.
2. `applyCalibration()` now returns only the calibrated result from the sensor front. It does not touch FRONT/BODY mode and does not subtract 75 mm.
3. The 75 mm offset is applied exactly once in `showMeasurementResult()`:
   - RAW mode: no calibration and no offset,
   - normal calibrated result: offset only when TS4 sets BODY,
   - normal result without valid calibration: also with offset if BODY is enabled.
4. The offset direction is subtractive: FRONT shows `frontMm`, BODY shows `frontMm - 75 mm`, limited to 0.
5. The TS4 banner was changed to the requested UI: `0 _ 75` = 75 mm offset disabled, `1 _ 75` = 75 mm offset enabled. The second digit is blanked with BCD `0x0F`.

Test:

1. Disable RAW, because RAW intentionally does not show the offset.
2. Make a measurement, for example at 300 mm in FRONT mode.
3. Press TS4. It should show `1 _ 75`.
4. Make the same measurement. The result should be about 75 mm lower.
5. Press TS4. It should show `0 _ 75`.
6. Make the same measurement. The result should return to the value without offset.

Note: if you are in RAW mode, TS4 will not change the reading because RAW by definition shows raw measurement without calibration and without offset.

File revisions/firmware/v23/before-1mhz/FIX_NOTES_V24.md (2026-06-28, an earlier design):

# NearSens v24 five-point calibration

Changes compared with v23:

1. Calibration now has five points: 100, 200, 300, 400 and 500 mm.
2. The calibration wizard supports the cyclic point list `100 -> 200 -> 300 -> 400 -> 500`. The start is still set to 300 mm because it is the most practical correction point. After entering the wizard, TS4 goes through `400 -> 500 -> 100 -> 200 -> 300`.
3. EEPROM format was bumped to v11 and stores all five raw calibration values and five validity flags.
4. Old EEPROM v10 data with 100/300/500 mm points is read and migrated to v11 on first startup after update.
5. Measurement correction selects the best available pair of calibration points. If only one valid point is available, the firmware still uses single-point offset correction as in the previous fallback behavior.

Test after upload:

1. Enter calibration by holding TS3+TS4.
2. Select point 100, 200, 300, 400 or 500 mm with TS4.
3. Confirm the measurement for the selected point with TS3.
4. After all points are calibrated, check control measurements at 100, 200, 300, 400 and 500 mm.
5. RAW mode still shows raw measurement without calibration and without the 75 mm offset.

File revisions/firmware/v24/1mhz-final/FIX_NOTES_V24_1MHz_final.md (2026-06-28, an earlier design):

# NearSens v24 1 MHz final

This package is a full Arduino sketch, not a single header file.

Settings before upload:

1. Board: ATtiny1626 with megaTinyCore.
2. Clock: 1 MHz internal.
3. Programmer/upload: same as before, jtag2updi/UPDI.
4. After upload, old calibration will be ignored because EEPROM_VERSION was bumped to 11.

What changed compared with v23:

1. The whole package was fixed, not only NearSens.h.
2. ADC is configured directly for fast reads at 1 MHz.
3. 100/300/500 mm calibration selects the cluster closest to the known calibration point, instead of always taking the first stable cluster.
4. A check was added so calibration does not store a stable false 300 mm echo as the 500 mm point.
5. Measurement and calibration clusters are separated. Normal measurement is tighter, calibration is more tolerant.
6. The 75 mm offset still works only in the normal result. RAW has no offset and no calibration.

Test procedure:

1. Upload the firmware.
2. After startup, check `8888`.
3. Enable RAW and check distances.
4. Enter calibration.
5. Store the selected calibration points.
6. Compare RAW and normal mode results.
7. Store 300 mm as the first point.

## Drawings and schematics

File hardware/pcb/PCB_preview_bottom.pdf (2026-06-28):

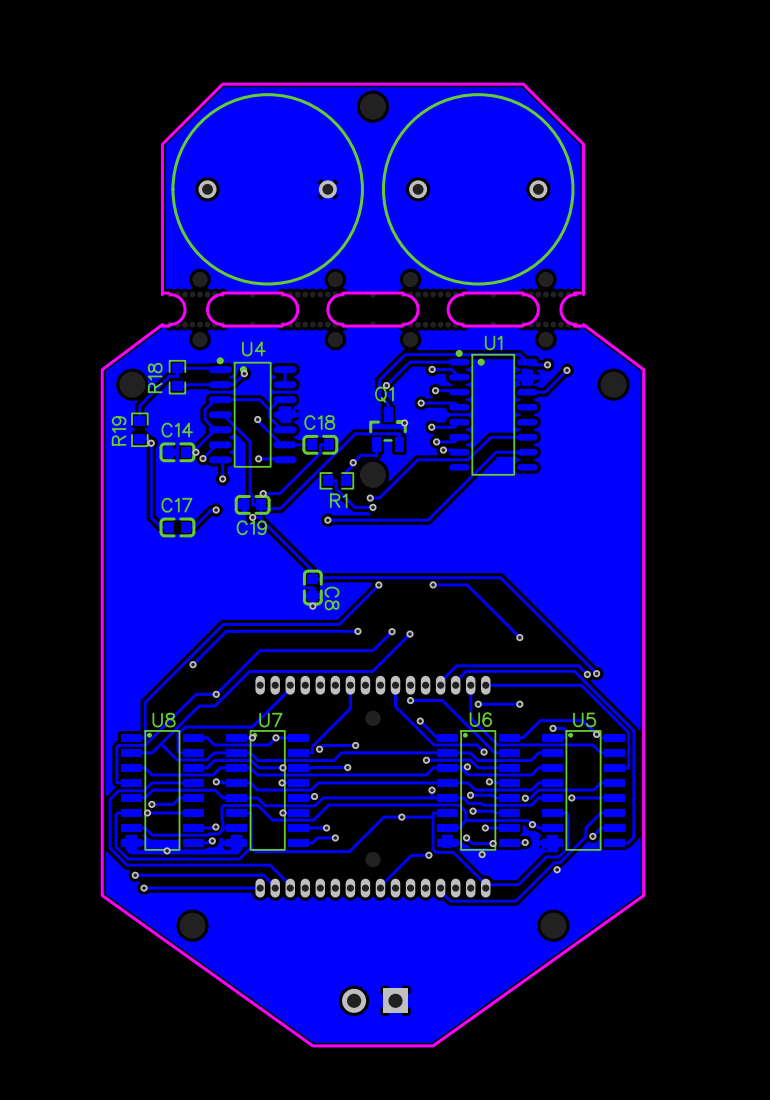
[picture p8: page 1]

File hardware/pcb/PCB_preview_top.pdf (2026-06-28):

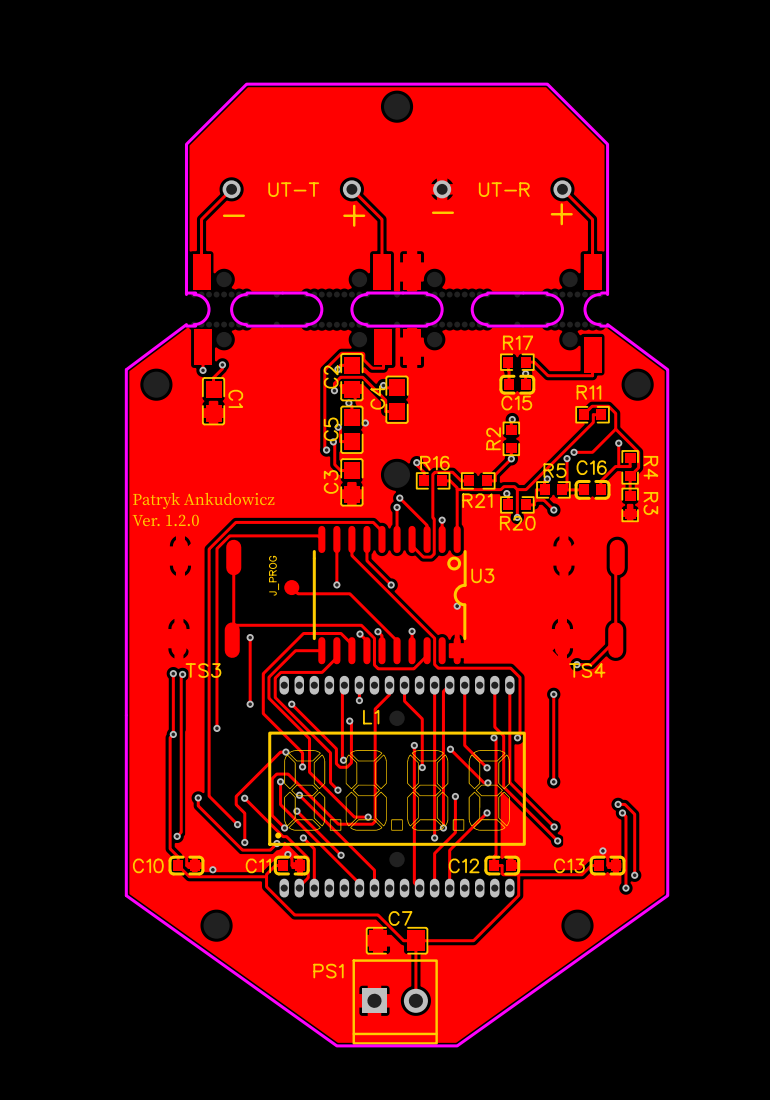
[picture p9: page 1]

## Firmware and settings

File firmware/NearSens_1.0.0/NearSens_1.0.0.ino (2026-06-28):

/*
  NearSens 1.0.0

  Firmware for prototype version v1.0.0. The code handles ultrasonic
  measurement, five-point 100-500 mm calibration, EEPROM storage,
  RAW mode, 75 mm correction and LCD codes.

  Version v1.0.0 was compiled for a 5 MHz clock.
  This file does not force the microcontroller clock. The clock setting
  is selected in Arduino IDE/megaTinyCore before compilation.
*/

#include "NearSens.h"


void setup() {
  configurePins();
  configureAdc();
  loadCalibration();
  setMax232Power(false);
  setAdcPower(false);

  uint32_t nowMs = millis();
  startupUntilMs = nowMs + STARTUP_DISPLAY_MS;
  buttonLockoutUntilMs = startupUntilMs;
  lastUserActivityMs = nowMs;
  displayMode = DISPLAY_IDLE;

  lcdShowValue(8888);
  physicallyDisplayedValue = 8888;
}

void loop() {
  serviceBackplane();
  serviceMeasureAnimation();
  serviceButtons();
  serviceDisplay();
  serviceDeepSleep();
  idleUntilInterrupt();
}

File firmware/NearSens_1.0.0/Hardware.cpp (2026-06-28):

#include "NearSens.h"

#include <avr/interrupt.h>

ISR(PORTA_PORT_vect) {
  PORTA.INTFLAGS = PIN_TS3_bm | PIN_TS4_bm;
}

void configurePins() {
  VPORTA.OUT &= ~(PIN_TX_T1_bm | PIN_TX_T2_bm);
  VPORTA.OUT |= PIN_MAX_ACTIVE_bm;
  VPORTB.OUT &= ~(PIN_LCD_BP_bm | PIN_LCD_LD1_bm | PIN_LCD_LD2_bm |
                  PIN_LCD_LD3_bm | PIN_LCD_LD4_bm | PIN_LCD_BL_bm);
  VPORTC.OUT &= ~LCD_BCD_MASK;

  PORTA.DIRSET = PIN_TX_T1_bm | PIN_TX_T2_bm | PIN_MAX_ACTIVE_bm;
  PORTA.DIRCLR = PIN_ECHO_bm | PIN_TS3_bm | PIN_TS4_bm;
  PORTB.DIRSET = PIN_LCD_BP_bm | PIN_LCD_LD1_bm | PIN_LCD_LD2_bm |
                 PIN_LCD_LD3_bm | PIN_LCD_LD4_bm | PIN_LCD_BL_bm;
  PORTC.DIRSET = LCD_BCD_MASK;

  PORTA.PIN1CTRL = PORT_PULLUPEN_bm;
  PORTA.PIN2CTRL = PORT_PULLUPEN_bm;
  PORTA.PIN6CTRL = PORT_ISC_INPUT_DISABLE_gc;
}

void configureAdc() {
  analogReference(VDD);
  analogReadResolution(10);
  ADC0.MUXPOS = ECHO_ADC_MUXPOS;
  setAdcPower(true);
  (void)readEchoAdc();
  setAdcPower(false);
}

void setAdcPower(bool on) {
  if (on) {
    ADC0.MUXPOS = ECHO_ADC_MUXPOS;
    ADC0.CTRLA |= (ADC_ENABLE_bm | ADC_LOWLAT_bm);
    adcPowered = true;
  } else {
    while (ADC0.COMMAND & ADC_START_gm) {
    }
    ADC0.CTRLA &= ~ADC_ENABLE_bm;
    adcPowered = false;
  }
}

void prepareMeasurementPower() {
  setMax232Power(true);
  setAdcPower(true);

  uint32_t settleUntilMs = millis() + MEASURE_POWER_SETTLE_MS;
  while (!dueMs(millis(), settleUntilMs)) {
    serviceBackplane();
  }

  for (uint8_t i = 0; i < ADC_WARMUP_READS; i++) {
    (void)readEchoAdc();
    serviceBackplane();
    delayMicroseconds(40);
  }
}

void finishMeasurementPower() {
  VPORTA.OUT &= ~(PIN_TX_T1_bm | PIN_TX_T2_bm);
  setAdcPower(false);
  setMax232Power(false);
}

void idleUntilInterrupt() {
  if (measuringNow) {
    return;
  }

  set_sleep_mode(SLEEP_MODE_IDLE);
  sleep_enable();
  sleep_cpu();
  sleep_disable();
}

void serviceDeepSleep() {
  if (measuringNow || displayMode == DISPLAY_BANNER ||
      calibrationWizardActive || ts3ClickCount != 0) {
    return;
  }
  if (!dueMs(millis(), startupUntilMs) || !dueMs(millis(), buttonLockoutUntilMs)) {
    return;
  }
  if (dueMs(millis(), lastUserActivityMs + DEEP_SLEEP_TIMEOUT_MS)) {
    enterDeepSleep();
  }
}

void enterDeepSleep() {
  deepSleeping = true;
  VPORTA.OUT &= ~(PIN_TX_T1_bm | PIN_TX_T2_bm);
  setAdcPower(false);
  setMax232Power(false);
  lcdSetBlank(true);
  VPORTB.OUT &= ~PIN_LCD_BP_bm;
  bpLevel = false;

  PORTA.INTFLAGS = PIN_TS3_bm | PIN_TS4_bm;
  PORTA.PIN1CTRL = PORT_PULLUPEN_bm | PORT_ISC_LEVEL_gc;
  PORTA.PIN2CTRL = PORT_PULLUPEN_bm | PORT_ISC_LEVEL_gc;

  set_sleep_mode(SLEEP_MODE_PWR_DOWN);
  sleep_enable();
  sleep_cpu();
  sleep_disable();

  wakeFromDeepSleep();
}

void wakeFromDeepSleep() {
  PORTA.PIN1CTRL = PORT_PULLUPEN_bm;
  PORTA.PIN2CTRL = PORT_PULLUPEN_bm;
  PORTA.INTFLAGS = PIN_TS3_bm | PIN_TS4_bm;

  deepSleeping = false;
  lastBpToggleUs = micros();
  markUserActivity();
  buttonLockoutUntilMs = millis() + BUTTON_LOCKOUT_MS;
  ts3WasPressed = (VPORTA.IN & PIN_TS3_bm) == 0;
  ts4WasPressed = (VPORTA.IN & PIN_TS4_bm) == 0;
  ts3HoldTriggered = true;
  ts4HoldTriggered = true;
  chordWasPressed = ts3WasPressed && ts4WasPressed;
  chordHoldTriggered = chordWasPressed;
  showIdleMarker();
}

void markUserActivity() {
  lastUserActivityMs = millis();
}

void setMax232Power(bool on) {
  if (on) {
    VPORTA.OUT &= ~PIN_MAX_ACTIVE_bm;
  } else {
    VPORTA.OUT |= PIN_MAX_ACTIVE_bm;
  }
}

void sendBurst() {
  uint8_t idleOut = VPORTA.OUT & ~(PIN_TX_T1_bm | PIN_TX_T2_bm);
  uint8_t t1Out = idleOut | PIN_TX_T1_bm;
  uint8_t t2Out = idleOut | PIN_TX_T2_bm;

#if F_CPU == 1000000L
  uint8_t count = TX_CYCLES;
  __asm__ __volatile__(
    "1:" "\n\t"
    "out %[port], %[t1]" "\n\t"
    "nop" "\n\t"
    "nop" "\n\t"
    "nop" "\n\t"
    "nop" "\n\t"
    "nop" "\n\t"
    "nop" "\n\t"
    "nop" "\n\t"
    "nop" "\n\t"
    "nop" "\n\t"
    "nop" "\n\t"
    "nop" "\n\t"
    "out %[port], %[t2]" "\n\t"
    "nop" "\n\t"
    "nop" "\n\t"
    "nop" "\n\t"
    "nop" "\n\t"
    "nop" "\n\t"
    "nop" "\n\t"
    "nop" "\n\t"
    "nop" "\n\t"
    "nop" "\n\t"
    "dec %[count]" "\n\t"
    "brne 1b" "\n\t"
    "out %[port], %[idle]" "\n\t"
    : [count] "+r" (count)
    : [port] "I" (_SFR_IO_ADDR(VPORTA.OUT)),
      [t1] "r" (t1Out),
      [t2] "r" (t2Out),
      [idle] "r" (idleOut)
  );
#else
  for (uint8_t i = 0; i < TX_CYCLES; i++) {
    VPORTA.OUT = t1Out;
    delayMicroseconds(TX_HALF_PERIOD_US);
    VPORTA.OUT = t2Out;
    delayMicroseconds(TX_HALF_PERIOD_US);
  }

  VPORTA.OUT = idleOut;
#endif
}

uint16_t readEchoAdc() {
  if (!adcPowered) {
    setAdcPower(true);
  }

  while (ADC0.COMMAND & ADC_START_gm) {
  }
  ADC0.MUXPOS = ECHO_ADC_MUXPOS;
  ADC0.INTFLAGS = ADC_RESRDY_bm;
  ADC0.COMMAND = ECHO_ADC_COMMAND;
  while (!(ADC0.INTFLAGS & ADC_RESRDY_bm)) {
  }
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

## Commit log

2026-03-17 0.9.0
    It's a first approach to this project and more of a concept than something perfect.
    Timelapse:
    https://lapse.hackclub.com/timelapse/m5912Vep-0yq
    [bom(Local-shop).csv]
2026-04-03 Add NearSens schematics and timelapse
    Add new NearSens schematic files for v0.10.0 (SVG and PNG, dated 2026-04-03), include the existing v0.9.0 PNG schematic, and add a timelapse video (timelapses/0.9.0-10.03.2026.mp4) plus timelapses/.g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
2026-05-19 Add BOMs and PCB/schematic exports
    Add multiple BOM spreadsheets and a reworked local-shop CSV, plus PCB and schematic exports for NearSens WETI revisions. New files: hardware/bom/Aliexpress.ods, hardware/bom/bom(Local-shop).ods, hardware/bom/stasis-bom.csv, and updated hardware/bom/bom(Local-shop).csv (rewritten layout and item entries). Add PCB JSON/ZIP and schematic SVG exports for versions 0.12.0, 0.13.0 and 0.14.0 (PCB_PCB_WETI-NearSens_2026-04-07/11/20.json/.zip and corresponding Schematic SVGs), and an additional PCB screenshot PNG. These changes provide updated BOM data and board/schematic export artifacts for the project releases.
    [Aliexpress.ods, bom(Local-shop).csv, bom(Local-shop).ods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]
2026-05-25 Add NearSens schematics and update BOM
    Add new schematic files for WETI-NearSens (Schematic_2026-05-25-4.net and Schematic_WETI-NearSens_2026-05-25-4.svg) and commit an updated BOM spreadsheet (hardware/bom/bom(Local-shop).ods). Remove ou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
    [BOM_WETI-NearSens_2026-05-22.csv, bom(Local-shop).csv, bom(Local-shop).ods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]
2026-06-28 NearSens 1.0.0
    [Aliexpress.ods, NearSens_BOM_v1.0.0.csv, NearSens_bracket_v1.0.0.stl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]
